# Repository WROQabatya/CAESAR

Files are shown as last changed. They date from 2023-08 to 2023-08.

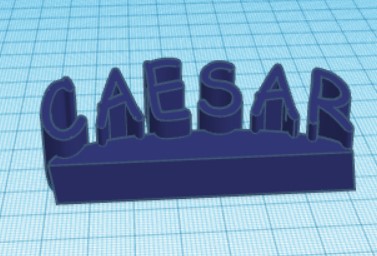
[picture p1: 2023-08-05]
3dDesignes/image/RoboName.jpg

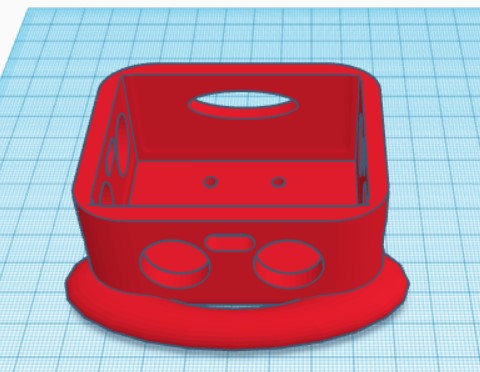
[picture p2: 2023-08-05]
3dDesignes/image/dSensorMount.jpg

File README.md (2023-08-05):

Title: Microcontroller-Based Vehicle Control System: A C++ and Ultrasonic Sensor Approach

Introduction:
Our vehicle, named CAESAR , is an innovative microcontroller-based system that utilizes Arduino as the central controller. The Arduino microcontroller is programmed using C++ language to control various components, including motors, steering wheels, and sensors like Ultrasonic sensors. We have opted not to incorporate a Raspberry Pi or gyro sensor in our project.

C++ Code Structure:
The C++ code is thoughtfully organized into sections, each dedicated to specific functionalities.

Servo Motor and Ultrasonic Sensor Control:
We employ libraries to control the servo motor movement and interface with Ultrasonic sensors. These sensors play a crucial role in detecting obstacles and determining the vehicle's movement directions.

Global Variables:
Descriptive global variables, such as "normalSpeed" and "turnSpeed," are defined to manage the vehicle's speed and turning behavior, respectively.

Ultrasonic Sensor Functions:
Key functions, including "turnLeft()" and "turnRight()", leverage readings from Ultrasonic sensors to determine the appropriate direction for the vehicle. The Ultrasonic sensor values guide counter-clockwise and clockwise turns. Additionally, functions like "getDistance()", "getForward()", "getBack()", "getRight()", and "getLeft()" are implemented to read data from individual Ultrasonic sensors.

Setup and Main Logic:
The "setup()" function handles necessary configurations for the system, while the main logic is implemented inside the "loop()" function. The loop function continuously executes, enabling the vehicle to react to real-time changes detected by the Ultrasonic sensors.

No Gyro Sensor Integration:
In contrast to some designs, we have opted not to use a gyro sensor in our project. Instead, we focus solely on utilizing Ultrasonic sensors for obstacle detection and navigation.

Conclusion:
Our microcontroller-based vehicle control system showcases the capabilities of Arduino and C++ programming in managing various vehicle components. With Ultrasonic sensors serving as the primary input, our CAESAR vehicle demonstrates reliable obstacle avoidance and navigation capabilities.

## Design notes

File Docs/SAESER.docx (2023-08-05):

Stages of making a SAESER

ENG.AHMAD

HISHAM

MAJD

KANAAN

Introduction

WRO Future Engineers -Selft Driving car

selft driving car

When we talk about competitions that are concerned with the field of robotics, we must talk about The World Robot Olympiad (WRO) , which was launched for the youth category. China, Japan and Singapore, and these four countries are the founding countries of this Olympiad (now known as the WRO Advisory Board).

Problems

Our Competition:

We are competing in this competition in the Future Engineers category It revolves around designing a self-driving robot that can overcome the obstacles and problems it encounters in the least possible time, based on artificial intelligence and machine learning.

Contest idea:

The environment of this competition consists of a circuit surrounded by an external wall, inside which there is an internal wall. As for the competition, it consists of one stage in which the robot runs at a rate of 3 laps that it must complete in 3 minutes as a maximum.

STAGE

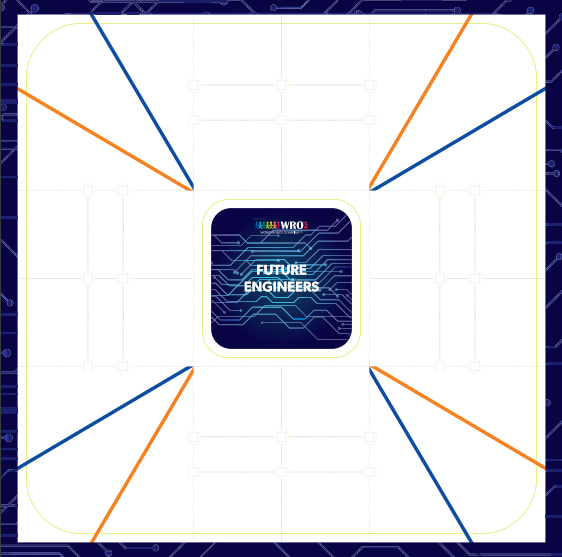
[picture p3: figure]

Hypotheses

During our work and the manufacture of the robot, we encountered many problems, and it is normal for such matters to happen in this field. They must be resolved with patience, effort, research, and the use of time to find an accurate solution.

Hypotheses and questions:

How to identify the appropriate electronics and employ them properly?

How can machine learning be employed in the work of a robot?

How can you complete the race and avoid mistakes?

How can a software algorithm be found to make the performance professional?

How to find solutions to all possible possibilities?

Methodology

The design phase of the robot was divided into 2 parts

namely:

. Hardware 1

. Software2

First, the electronics were selected according to the "WRO" competition.

Secondly, we start creating 3D designs to be placed on most electronic pieces to install or otherwise.

Thirdly, we start installing the 3D designs of electronics on the robot and conducting a preliminary test for it.

Finally, we start writing the software code and employing these electronics in it.

The Electronics:

Use Electronics:

• Arduino Mega 2560

• L298N Motor Driver

• Ultrasonic Distance sensor x(4)

• DC gear motor 12v 60 RPM

• s3003 servo motor

• Power Supply

• Wires

• Wheels

Arduino Mega 2560:

• Microcontroller: ATmega2560.

• INPUT VOLTAGE (LIMIT): 6-20V

• Flash Memory: 256 KB of which 8 KB used by bootloader.

• Analog In Pin: 16.

• Digital I/O Pins: 54 (of which 15 provide PWM output).

• Weight: 37g.

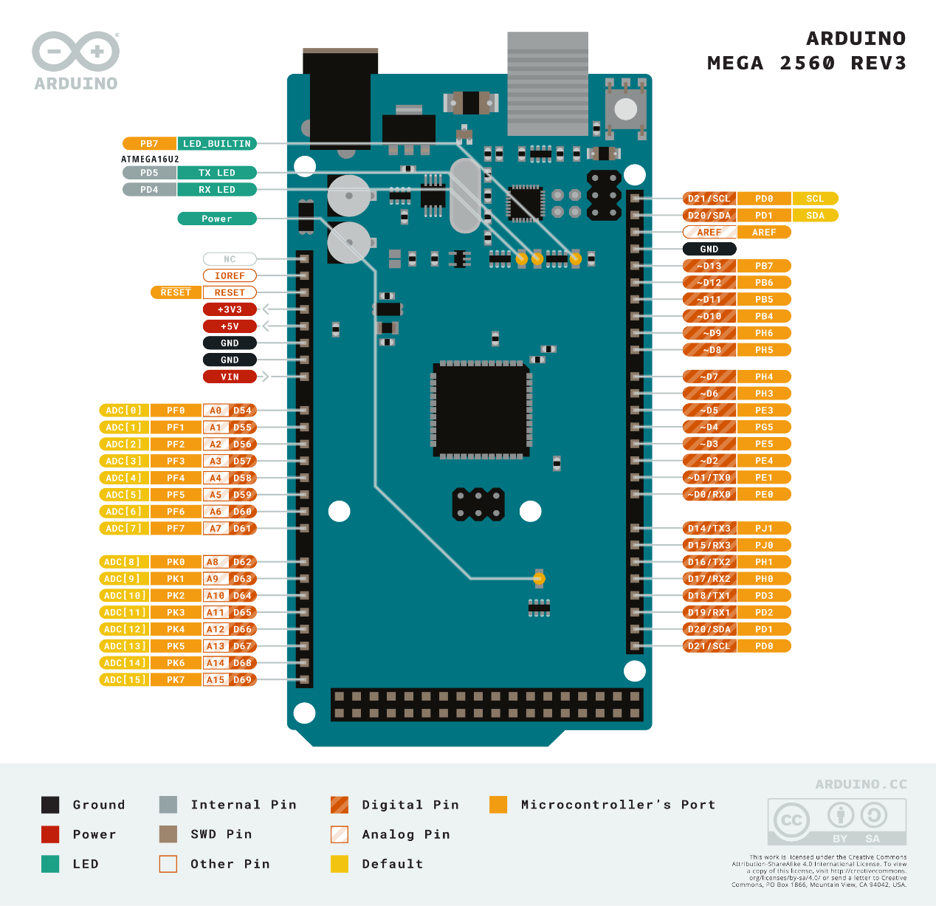
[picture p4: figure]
صورة تحتوي على نص, لقطة شاشة, برمجيات, دائرة كهربائية تم إنشاء الوصف تلقائياً

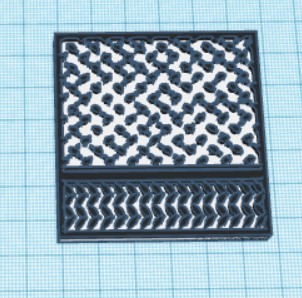
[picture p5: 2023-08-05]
3dDesignes/image/kofeia.jpg

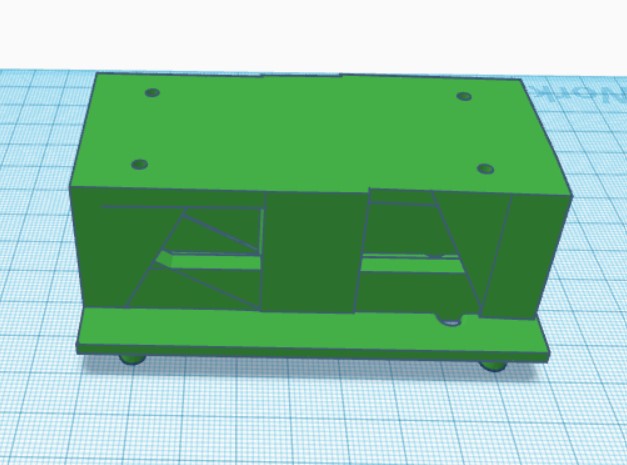
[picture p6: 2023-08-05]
3dDesignes/image/ArduinoHolder.jpg

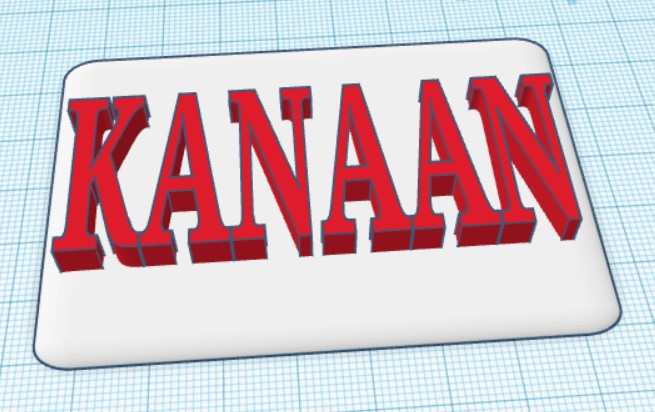
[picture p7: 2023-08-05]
3dDesignes/image/TeemName.jpg

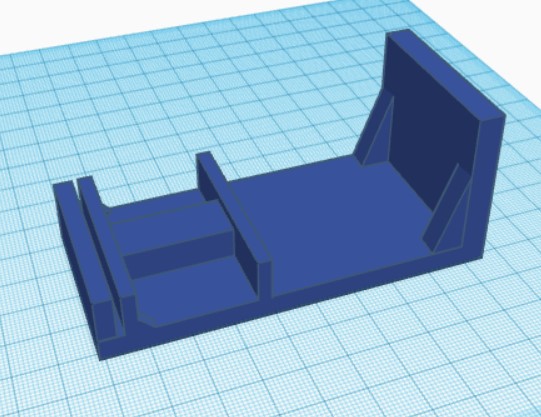
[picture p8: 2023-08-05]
3dDesignes/image/AudioStand.jpg

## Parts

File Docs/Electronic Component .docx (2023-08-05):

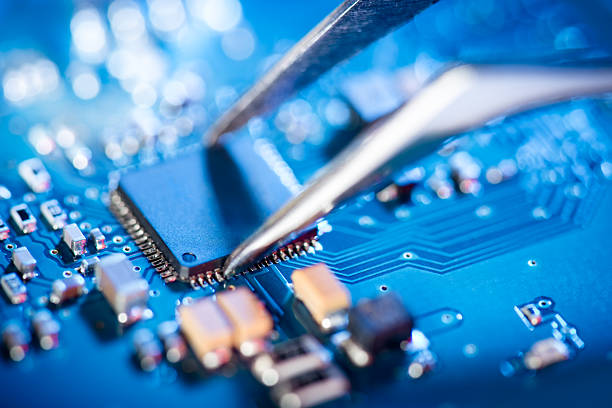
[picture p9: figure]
صورة تحتوي على دائرة كهربائية, الهندسة الإلكترونية, مكون إلكتروني, مكونات الدائرة الكهربائية تم إنشاء الوصف تلقائياً

Electronic Parts

KANAAN TEAM

Content

- Main Diagram
- Arduino Mega 2560
- L298N Motor Driver
- DC voltage Buck
- DC Encoder Motor
- Servo Motor
- Battery

Main Diagram

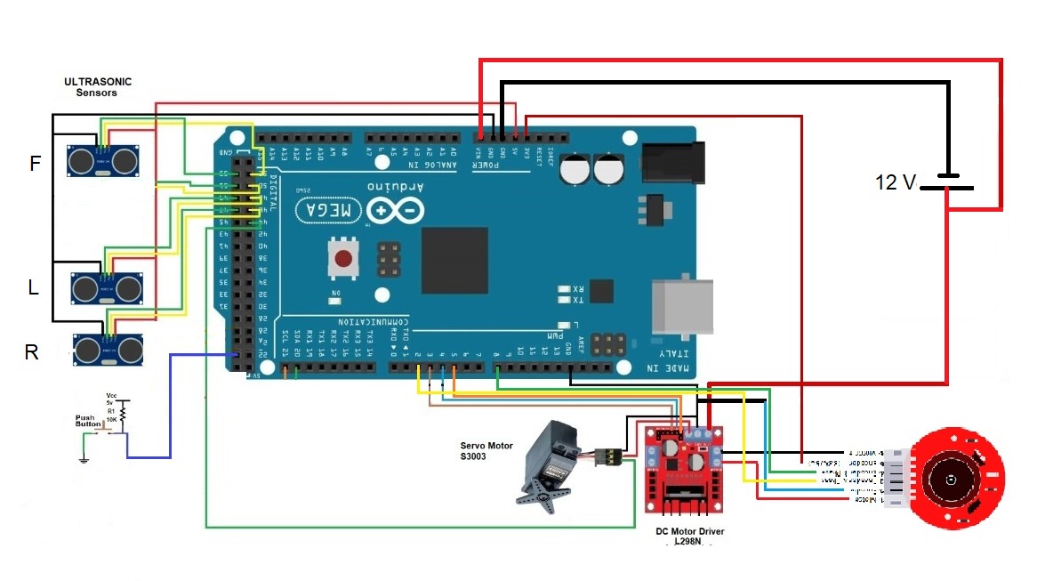
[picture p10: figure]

The electronic diagram illustrates the interconnection mechanism between the controllers and how the Arduino controller is linked to the Ultrasonic sensors and motor driver. The motor driver is responsible for governing both the DC motor and the servo.

Arduino Mega 2560

The Arduino microcontroller plays a pivotal role in controlling diverse electronic components through the following processes:

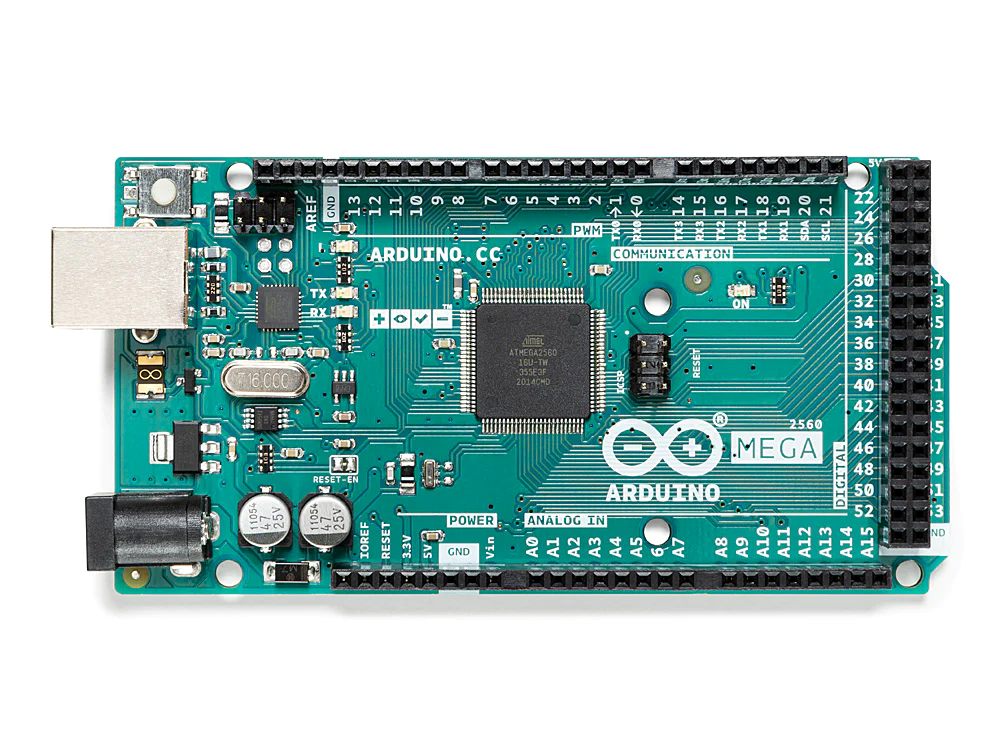
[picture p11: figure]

Initially, it supervises the servo motor and DC motor by sending commands to the motor driver.

Subsequently, it measures the distances recorded by the front, back, and side ultrasonic sensors.

Furthermore, it regulates the RGB LEDs, granting the ability to manipulate their colors.

Lastly, it detects the push button to activate the vehicle's functions. It is noteworthy that the Arduino Nano has been replaced by the Arduino Mega. This change was made due to the benefits of using the Arduino Mega, which offers individual ports for each function without requiring multiplexing. This configuration allows for more efficient use of PWM (Pulse Width Modulation) capabilities. Additionally, the system reads the switch to facilitate code changes.

L298N Motor Driver

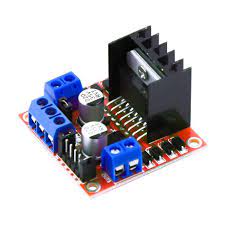
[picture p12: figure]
صورة تحتوي على مكونات الدائرة الكهربائية, مكون إلكتروني, دائرة كهربائية, مكون الدائرة السلبية تم إنشاء الوصف تلقائياً

The motor driver serves a dual purpose, enabling both speed control for the DC motor and facilitating forward and backward motion, while also governing the movement of the servo motor.

Ultrasonic Sensors

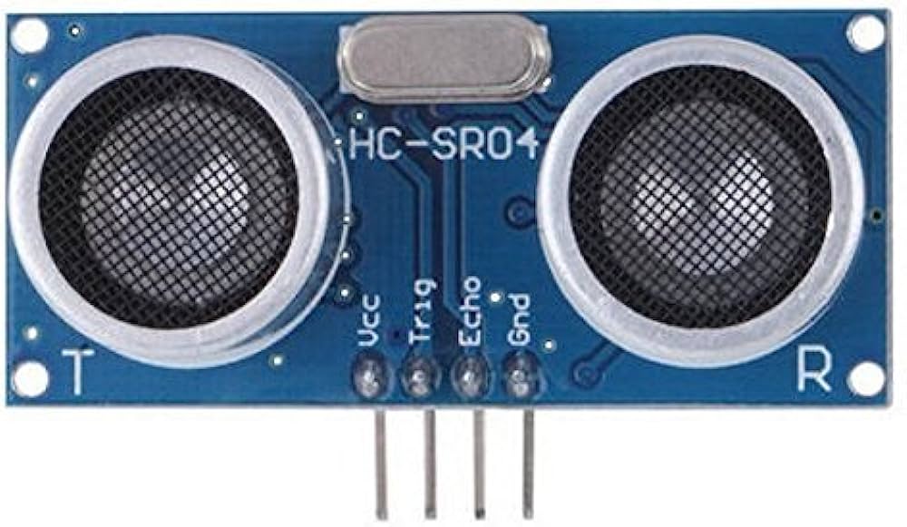
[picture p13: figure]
صورة تحتوي على الإلكترونيات, مكبر الصوت, معدات الصوت, صندوق الصوت تم إنشاء الوصف تلقائياً

A trio of sensors is employed, with one positioned at the front and two on the sides. These ultrasonic sensors play a crucial role in determining distances and the direction of the vehicle's movement, along with providing valuable insights into other pertinent aspects.

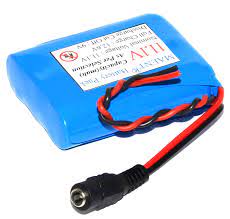
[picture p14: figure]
صورة تحتوي على نص, كابل, البطارية تم إنشاء الوصف تلقائياً

Battery

The vehicle relies on a battery to supply essential power. This battery configuration comprises three lithium batteries interconnected in series.

DC voltage Buck

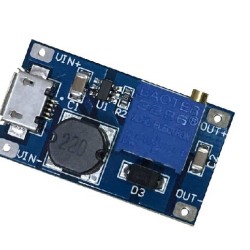
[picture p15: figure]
صورة تحتوي على مكون إلكتروني, الهندسة الإلكترونية, الإلكترونيات, مكونات الدائرة الكهربائية تم إنشاء الوصف تلقائياً

This circuit is designed to reduce voltage, as it was used to supply power to the Servo Motor.

DC Encoder Motor

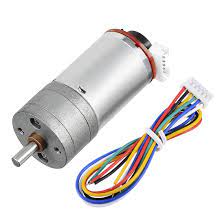
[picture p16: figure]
صورة تحتوي على كابل, أسطوانة, الأسلاك الكهربائية, فضة/ لون فضي تم إنشاء الوصف تلقائياً

The DC motor is physically linked to the rear wheels, enabling the vehicle's motion.

The reason for using an Encoder is to monitor the motor's direction and movement, which proves instrumental in controlling the overall movement of the vehicle.

صورة تحتوي على نص, أداة, كابل, البطارية تم إنشاء الوصف تلقائياً

Servo Motor

The servo motor assumes the responsibility of directing the vehicle by manipulating the steering wheel.

THANK YOU

KANAAN TEAM

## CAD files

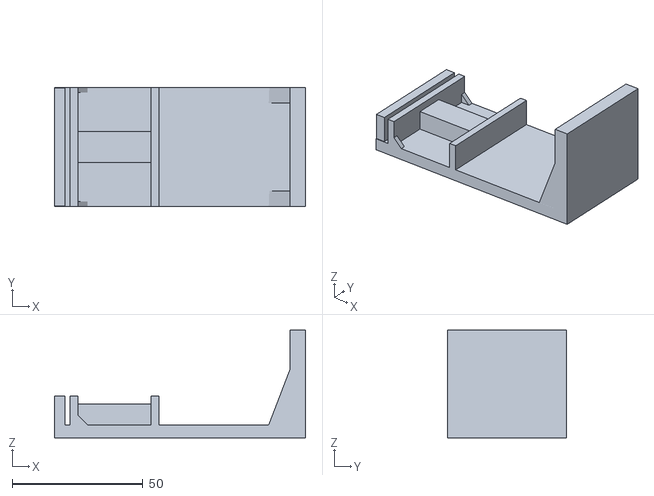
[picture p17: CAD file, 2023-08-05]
3dDesignes/STL/AudioStand (1).stl
96.0 x 45.5 x 41.3

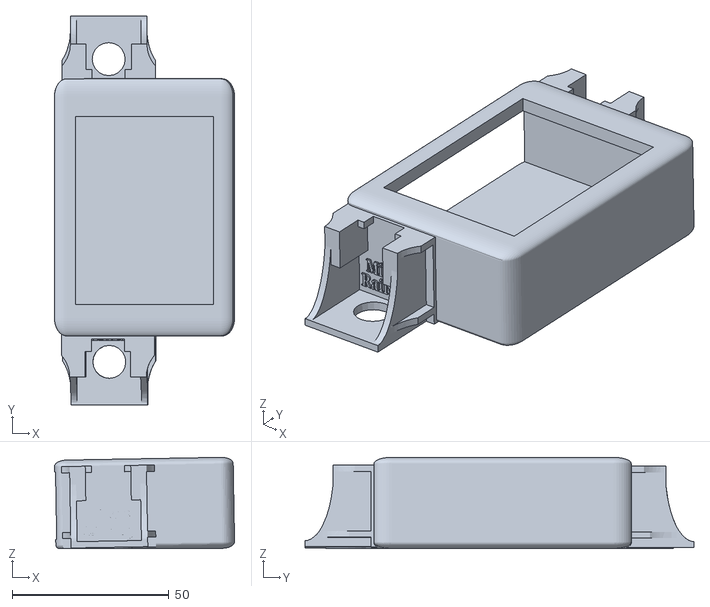
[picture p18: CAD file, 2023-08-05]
3dDesignes/STL/BattaryHolder (2).stl
57.4 x 124.0 x 29.1

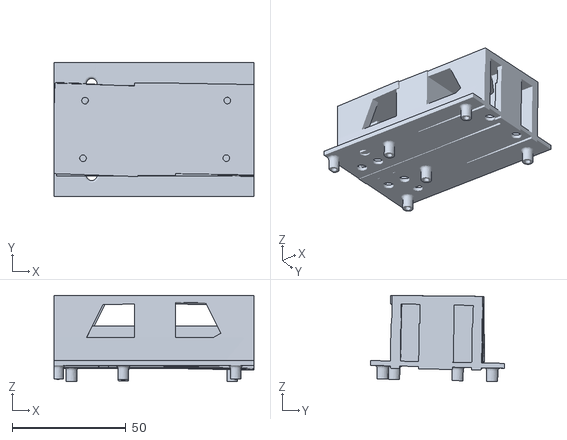
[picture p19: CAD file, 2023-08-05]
3dDesignes/STL/ArduinoHolder23 (1).stl
88.1 x 59.0 x 37.9

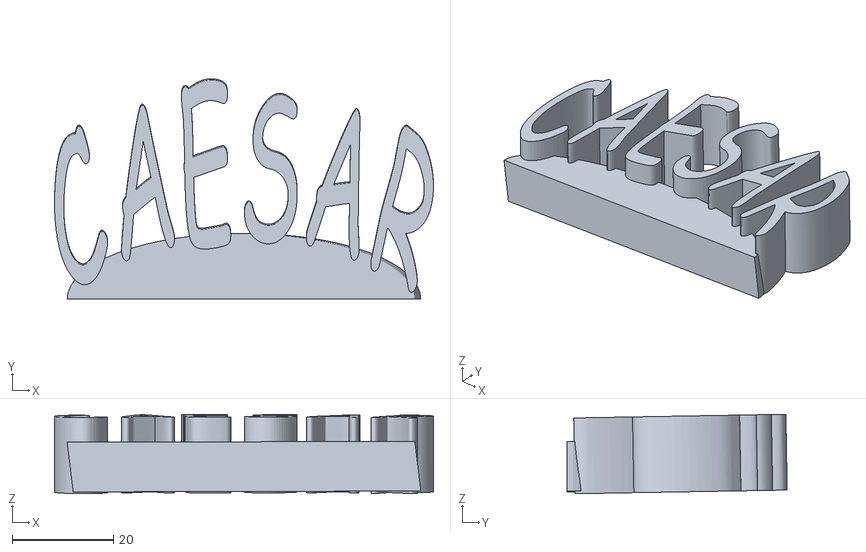
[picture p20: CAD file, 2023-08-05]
3dDesignes/STL/RoboName23 (2).stl
75.0 x 43.6 x 15.7

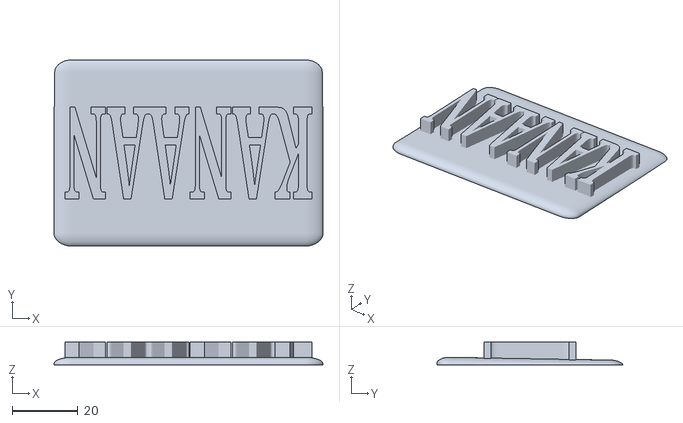
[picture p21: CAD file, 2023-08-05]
3dDesignes/STL/TeemName (1).stl
82.0 x 56.8 x 7.00

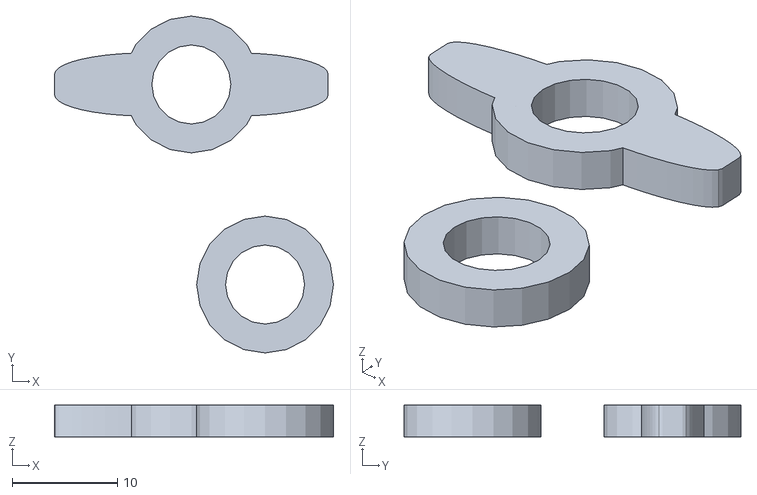
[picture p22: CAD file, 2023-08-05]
3dDesignes/STL/buttonAndLedMount.stl
26.5 x 32.0 x 3.00

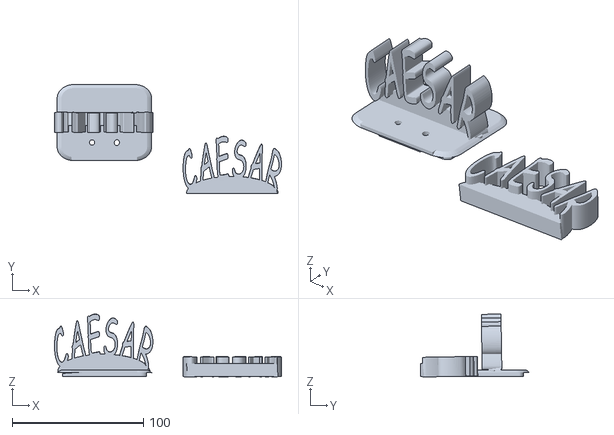
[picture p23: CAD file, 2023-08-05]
3dDesignes/STL/SensorsCover (1).stl
173.0 x 83.0 x 48.0

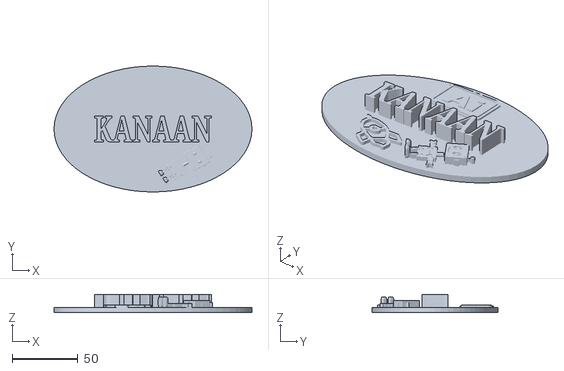
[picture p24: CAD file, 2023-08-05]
3dDesignes/STL/TeemLogo.stl
151.0 x 96.0 x 14.0

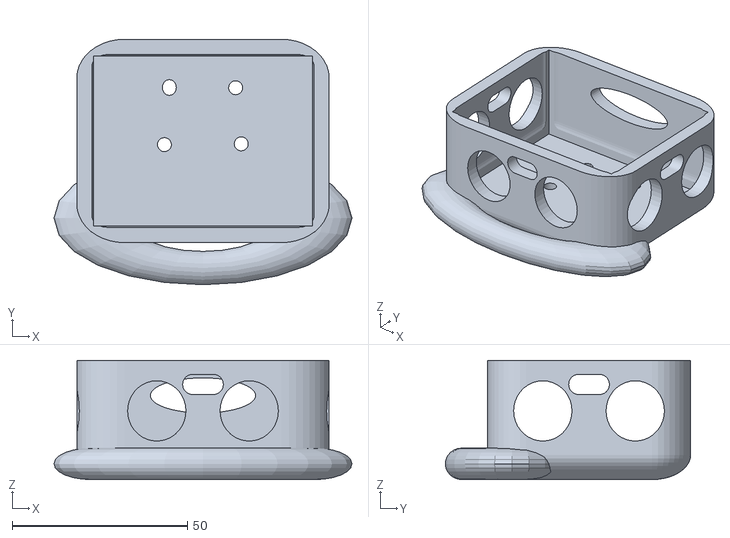
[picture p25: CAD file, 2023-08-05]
3dDesignes/STL/dSensorMount.stl
85.0 x 70.0 x 34.0

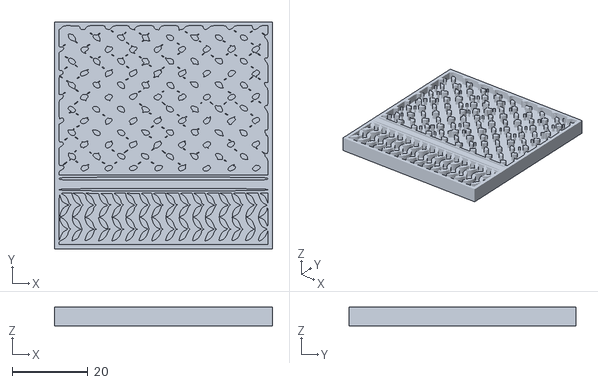
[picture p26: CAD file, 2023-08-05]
3dDesignes/STL/kofeia.stl
57.5 x 60.0 x 5.00

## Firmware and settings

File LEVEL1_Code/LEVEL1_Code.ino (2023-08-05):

#include <SoftwareSerial.h>
#include"DFRobotDFPlayerMini.h"

#include <Servo.h>
#include <math.h>
Servo Stearing ;

SoftwareSerial audioSerial(30, 31); // RX, TX
DFRobotDFPlayerMini myDFPlayer;

void speakInit(){
  audioSerial.begin(9600);
  if (!myDFPlayer.begin(audioSerial)) { Serial.println(F("DFPlayer Mini Error."));  }
  myDFPlayer.setTimeOut(500); //Set serial communictaion time out 500ms
  myDFPlayer.volume(25);
  }


int normalSpeed = 250;
int turnSpeed = 225;
int currentSpeed = 100;
int reverseSpeed = 50 ;
int isturn=0;
int canTurn=0;
int counterClockWise = 0;  // 0 init  1 clock  2 counterclockwise
int needTurn=0;
int LastState=0;
int CodeMOD=0;

volatile long encoderPos = 0;
String state ="9";
float distance;

// Motors 

#define encodPinA1      2                       // Quadrature encoder A pin
#define encodPinB1      8                       // Quadrature encoder B pin
#define PWM             5
#define M1              4                       // PWM outputs to L298N H-Bridge motor driver module
#define M2              3
#define Motor 44
#define BTN 13
#define MOD 14
#define LEDG 12
#define LEDB 11
#define LEDR 10

// distance 

#define TRIGGERF 52   //D6
#define ECHOF 53      //D7
#define TRIGGERL 48 //A0
#define ECHOL 49    //A1
#define TRIGGERR 50 //A2
#define ECHOR 51    //A3


unsigned long period;

// --- end distance

int x=0;
int counter = 0 ;


void setup() {
  // put your setup code here, to run once:

  pinMode(LEDR,OUTPUT);
  pinMode(LEDG,OUTPUT);
  pinMode(LEDB,OUTPUT);
  pinMode(MOD,INPUT);
  pinMode(BTN,INPUT);



  Stearing.attach(Motor);

  pinMode(M1,OUTPUT);
  pinMode(M2,OUTPUT);
  pinMode(encodPinA1, INPUT_PULLUP);                  // quadrature encoder input A
  pinMode(encodPinB1, INPUT_PULLUP);                  // quadrature encoder input B
  attachInterrupt(0, encoder, FALLING);               // update encoder position
  TCCR1B = TCCR1B & 0b11111000 | 1; 
 // set 31KHz PWM to prevent motor noise
  pinMode(BTN,INPUT);

  // distance 

  pinMode(ECHOL,INPUT);
  pinMode(TRIGGERL,OUTPUT);

 
  
  pinMode(ECHOF,INPUT);
  pinMode(TRIGGERF,OUTPUT);
  
  pinMode(ECHOR,INPUT);
  pinMode(TRIGGERR,OUTPUT);
  
  // -end distance

  Serial.begin (115200);  
  pinMode(Motor,OUTPUT);

 

  resetStearings(); 
 
if (!digitalRead(MOD)){digitalWrite(LEDB,HIGH);CodeMOD=0;}
else{digitalWrite(LEDG,HIGH);CodeMOD=1;}

   speakInit();
   myDFPlayer.play(3);

}
//   Distance Fun


void encoder()  {                                     // pulse and direction, direct port reading to save cycles
  if (PINB & 0b00000001)    encoderPos--;             // if(digitalRead(encodPinB1)==HIGH)   count ++;
  else                      encoderPos++;             // if(digitalRead(encodPinB1)==LOW)   count --;
}

float obstacleDist(int trig,int echo){
 digitalWrite(trig,LOW);
 delayMicroseconds(3);
 digitalWrite(trig,HIGH);
 delayMicroseconds(10);
 digitalWrite(trig,LOW);
 period=pulseIn(echo,HIGH);
 distance=float(period)/58.8;
  return distance;
  
  }


// End Distance Fun


// functions for dc motor

void Run(int out) {                                // to H-Bridge board
  if (out > 0) {
    analogWrite(PWM,out);
    digitalWrite(M1, HIGH);                             // drive motor CW
    digitalWrite(M2, LOW);
  }
  else {
     analogWrite(PWM,out);
     digitalWrite(M1, LOW);                             // drive motor CW
     digitalWrite(M2, HIGH);                        // drive motor CCW
  }
  
}


// functions to read ultrasonic sensors 
int getForward ()
{


int i = 0; 
int f = 0;
int tmp = 0;
tmp = obstacleDist(TRIGGERF,ECHOF);
while (i < 2)
{
  i++;
tmp = (obstacleDist(TRIGGERF,ECHOF) + tmp)/2;
}
 if (tmp > 250 ) {
    tmp = 150 ;  
  }

return  tmp;
}

int getLeft ()
{

int i = 0; 
int L = 0 ;
int  tmp = obstacleDist(TRIGGERL,ECHOL);
while (i < 2)
{

  i++;
  L=obstacleDist(TRIGGERL,ECHOL);
  if (L>tmp) {tmp=L;}
  
 
}
 
return tmp;
}

int getRight ()
{

int i = 0; 
int tmp = 0;
int R=0;
tmp = obstacleDist(TRIGGERR,ECHOR);
while (i < 2)
{
  i++;
  R=obstacleDist(TRIGGERR,ECHOR);
  if (R>tmp) {tmp=R;}

}
 

return tmp;
}




// end ultrasonic functions






void resetStearingi(){
  Stearing.write(120);
  MyDelay(2);
  if (counterClockWise == 0 || counterClockWise == 1)
  {
  Stearing.write(85);
  }
  else if (counterClockWise ==2)
  {
  Stearing.write(90);
  }
}

void resetStearings(){
  Stearing.write(120);
  MyDelay(2);
   
  Stearing.write(90);
  
}





void straightBack (int delta) 
{

 
  if (LastState == 0 || LastState == 1 ){

      encoderWalkStraight1(50,999);
      encoderPos = 0;
      Stearing.write(45);
      encoderWalkStraight1(53,999);
      encoderTurnBack(67 +delta);  
      resetStearingi();
      encoderWalkStraight1(10,999);
      Run(0);
      MyDelay(2);
      
      }
      else if (LastState == 5 )
      {
        
      encoderWalkStraight1(50,999);
      encoderPos = 0;
      Stearing.write(45);
      encoderWalkStraight1(53,999);      
      encoderTurnBack(10 +delta);   
      resetStearingi();
      encoderWalkStraight1(15,999);
      Run(0);
      MyDelay(2);
      
        }
counter++;
   
}


void straightBackRight (int delta) 
{
  int deltaStrightDifferenceVar = deltaStrightDifference(10);
  if (LastState == 5 || LastState == 0 ){
    
      encoderWalkStraight1(80,999);
      encoderPos = 0;
      Stearing.write(120);
      encoderWalkStraight1(27,999);      
      encoderTurnBackRight(47 +delta);  
      resetStearingi();
      MyDelay(2);
      revEncoderSpeed(25,reverseSpeed);
      }
      else if (LastState == 1 )
      {

      encoderWalkStraight1(50,999);
      encoderPos = 0;
      Stearing.write(120);
      encoderWalkStraight1(27,999);     
      encoderTurnBackRight(35 +delta);
      resetStearingi();
      MyDelay(2);
      revEncoderSpeed(15,reverseSpeed);      
        }
counter++;
}

void turnLeft1(int delta)
{
     // L = .785 * 50 = 39.25   "   "
encoderPos = 0;
    Stearing.write(45);
    drvEncoderSpeed(60,turnSpeed);
    Stearing.write(120);
    double revEncoderVar = 40 + delta  ;
    revEncoderSpeed(revEncoderVar,reverseSpeed);
    resetStearingi();
    MyDelay(2);
    drvEncoderSpeed(20,turnSpeed);
    Run(0);
    counter ++ ;
}

void turnRight1(int delta){
    encoderPos = 0;
    Stearing.write(120);
    drvEncoderSpeed(55,turnSpeed);
    Stearing.write(45);
    double revEncoderVar = 50+ 2*delta ;
    revEncoderSpeed(revEncoderVar,reverseSpeed);
    resetStearingi();
    MyDelay(2);
    drvEncoderSpeed(20,turnSpeed);
    Run(0);
    counter ++ ;
  }

void readState()
{

 if (Serial.available() > 0  ) {
      state = Serial.readStringUntil('\n');
      if(state =="1" || state =="5" ){cases(state);}
      state="9";
      Serial.end();
      Serial.begin(115200);
}
else{cases("1");}
}


void encoderTurnBack(int angle)
{
  int dis = angle * 0.76;
  Stearing.write(120);
  revEncoderSpeed(dis,reverseSpeed);
}

void encoderTurnBackRight(int angle)
{
  int dis = angle * 1.35;
  Stearing.write(45);
  revEncoderSpeed(dis,reverseSpeed);
}

void encoderWalkStraight1(int distance,int side){
   if (counterClockWise == 1 ) {
   int getRightVar =0; 

   drvEncoderSpeed(distance /4,normalSpeed);
   if (LastState == 1 )   // from red pillars
   {
       drvEncoderSpeed(distance /4,normalSpeed);
       getRightVar = getRight();
          
       if (side !=999 )
       {
        
          if (getRightVar<15){Stearing.write(45);MyDelay(3);Stearing.write(120);MyDelay(1);resetStearingi();}
          else if (getRightVar>25){Stearing.write(110);MyDelay(2);Stearing.write(60);MyDelay(1);resetStearingi();}
       }
       
       drvEncoderSpeed(distance /2,normalSpeed);

       }
      else if (LastState==5)
       {     

        int  getLeftVar = getLeft();
        drvEncoderSpeed(distance /4,normalSpeed);
        getLeftVar = getLeft();  
        if (side !=999  )
            {      
             if (getLeftVar<17 ){  Stearing.write(120);MyDelay(1);Stearing.write(60);MyDelay(1);resetStearingi();}
            }
        drvEncoderSpeed(distance /2,normalSpeed);
        
        }
        else
        {    
         drvEncoderSpeed(distance, normalSpeed);
        }
   }



   //********************************************


   
   else if (counterClockWise == 2 ) {

    int getLeftVar =0; 

   drvEncoderSpeed(distance /4,normalSpeed);
   if (LastState == 5 )   // from red pillars
   {
       drvEncoderSpeed(distance /4,normalSpeed);
       getLeftVar = getLeft();
       if (side !=999 )
       {
        
          if (getLeftVar<15){  Stearing.write(120);MyDelay(2);Stearing.write(60);MyDelay(2);resetStearingi();}
          else if (getLeftVar>20){  Stearing.write(60);MyDelay(3);Stearing.write(120);MyDelay(2);resetStearingi();}
       }


       drvEncoderSpeed(distance /2,normalSpeed);

       }
      else if (LastState==1)
       {    
 
        int  getRightVar = getRight();
        drvEncoderSpeed(distance /2,normalSpeed);
        getRightVar = getRight();
        if (side !=999  )
            {      
              if (getRightVar<17 ){Stearing.write(60);MyDelay(3);Stearing.write(120);MyDelay(2);resetStearingi();}
              if (getRightVar>22 ){Stearing.write(120);MyDelay(3);Stearing.write(60);MyDelay(2);resetStearingi();}
             }
        drvEncoderSpeed(distance /2,normalSpeed);

        }
        else
        {    
         drvEncoderSpeed(distance ,normalSpeed);
        }
   }
  }

void encoderWalkStraight(int distance,int side, int speed0){
   if (counterClockWise == 1 ) {
  
  int getLeftVar; 
  int  getRightVar;
  int getFrontVar;
   
  drvEncoderSpeed(distance /2,speed0);
       
   
       
       getLeftVar = getLeft(); 
          
       if ( getLeftVar <20 && side != 999)
       {
   
         Stearing.write(110);MyDelay(2);Stearing.write(60);MyDelay(1);resetStearingi();
        
          
         
       }
       else {getRightVar = getRight();
        
        if (getRightVar <17 && side != 999 ){   
          
          Stearing.write(45);MyDelay(3);Stearing.write(120);MyDelay(1);resetStearingi();}
       }


       drvEncoderSpeed(distance /2,speed0);
       getLeftVar = getLeft(); 
          
     
       

   }
   //********************************************


   
   else if (counterClockWise == 2 ) {

    int getLeftVar; 
    int  getRightVar;
    int getFrontVar;
   
       drvEncoderSpeed(distance /2,speed0);
       
       
       getRightVar = getRight();
       if (getRightVar <25 && side != 999)
       {
         Stearing.write(45);MyDelay(3);Stearing.write(100);MyDelay(1);resetStearingi();
        
          
         
       }
       else {getLeftVar = getLeft();
       
        
        if (getLeftVar <13 && side != 999){ 
          
         
        Stearing.write(105);MyDelay(2);Stearing.write(60);MyDelay(1);resetStearingi();
       }
      
       }
      


       drvEncoderSpeed(distance /2,speed0);
     
       
       
   }
  }
int deltaStrightDifference(int edgeThreshold)    // to calculate distance between vehicle and outer edge
{

  int delta = getForward()-edgeThreshold ; 
  
    if (delta > 0)
    {

      return delta ; 
    }
    else 
    {
      return 0 ;
    }
}



int CalculateWalkDifferenceDegree ( double disSide1,double disSide2,double encoderDis)
{
  int result  = asin((disSide1 - disSide2)/encoderDis)*(180/3.14);
  

  return (result);
}

void turnLeft(int delta)
{
     
  
    double revEncoderVar = 84+ delta ;
    Stearing.write(30);
    drvEncoderSpeed(revEncoderVar,turnSpeed);
    resetStearingi();
    MyDelay(2);
    counter ++ ;
    encoderWalkStraight(50,999,normalSpeed);
  
}

void turnRight(int delta)


{
    double revEncoderVar = 76+ delta ;
    Stearing.write(120);
    drvEncoderSpeed(revEncoderVar,turnSpeed);
    resetStearingi();
    MyDelay(2);
    counter ++ ;
    encoderWalkStraight(50,999,normalSpeed);
  
  
  
  
  }

void MyDelay(int cct)
{
  for (int i=0;i<cct;i++)
  {
    delay(50);
    }
  }


void drvEncoderSpeed(int cm,int speed0)
{
  encoderPos=0;
if (cm>25){
float enc = (cm-20)/0.077;
 
while (encoderPos < int(enc))
{
  Run(speed0);
  }

}
else 
{
float enc = (cm)/0.23;
while (encoderPos < int(enc))
{
  Run(speed0);
  }
  
  
}
}

void revEncoderSpeed(int cm,int speed0)
{
 encoderPos=0;
if (cm>25){
float enc = (cm-20)/0.077;
 
while (encoderPos < int(enc))
{
  Run(-speed0);
  }

}
else 
{
float enc = (cm)/0.23;
while (encoderPos < int(enc))
{
  Run(-speed0);
  }
  
  
}
}



void drvEncoderSpeed1(int cm,int speed0)
{
  encoderPos=0;
if (cm>25){
float enc = 2.3*((cm-20)/0.077);
 
while (encoderPos < int(enc))
{
  Run(speed0);
  }

}
else 
{
float enc = 2.3*((cm)/0.23);
while (encoderPos < int(enc))
{
  Run(speed0);
  }
  
  
}
}

void revEncoderSpeed1(int cm,int speed0)
{
 encoderPos=0;
if (cm>25){
float enc = 2*((cm-20)/0.077);
 
while (encoderPos < int(enc))
{
  Run(-speed0);
  }

}
else 
{
float enc = 2*((cm)/0.23);
while (encoderPos < int(enc))
{
  Run(-speed0);
  }
  
  
}
}

double tempEdgeDistance0 = 0;
double tempEdgeDistance1 = 0;



void loop() {




  
  while(x==6){
    int getRightVar = getRight() ;
    Serial.println(getRightVar);
   // MyDelay(4);
    double d= 1.414 * getRightVar ;
    Stearing.write(120);
    drvEncoderSpeed1((d/4),turnSpeed);
    drvEncoderSpeed1((d/5),turnSpeed);
    resetStearingi();
    drvEncoderSpeed1((d/3),turnSpeed);
    drvEncoderSpeed1((d/10),turnSpeed);  
    Stearing.write(45);
    drvEncoderSpeed1((d/3),turnSpeed);
     drvEncoderSpeed1((d/4),turnSpeed);
    resetStearingi();
    drvEncoderSpeed1(10,turnSpeed);
    LastState = 1;
    x=17;
    
  }
  
  // put your main code here, to run repeatedly:

        int z=0;int rpt = 0;int g =0;

        while (x==10){
      //  drvEncoder (40);
        turnLeft(0)
        ;x=2;}

        
if (!digitalRead(BTN) && CodeMOD ==0){digitalWrite(LEDG,HIGH);
   MyDelay(20);
    normalSpeed = 250;
    turnSpeed = 230;
      
      while (x==0){


 

        
              while (counterClockWise == 0) {
              if (getLeft()>80.0) {turnLeft(10);counterClockWise = 1; tempEdgeDistance0 = getRight();tempEdgeDistance1 = getRight(); drvEncoderSpeed(5,turnSpeed); }
              else if (getRight()>80.0 ){turnRight(10);counterClockWise = 2;tempEdgeDistance0 = getLeft();tempEdgeDistance1 = getLeft();drvEncoderSpeed(5,turnSpeed);  }
              else if (getForward()<40){Run(0);encoderWalkStraight(2,999,turnSpeed);encoderPos = 0;}
              else {Run(turnSpeed);encoderPos = 0; }
              continue;
              }
        

            

                   
            if ((counterClockWise == 1))
                  {
                    
               if (g< 100){g= getLeft();}


               if (g>77.0)
                    {  g=0;
                     tempEdgeDistance1 = getRight();      
                     int t = CalculateWalkDifferenceDegree(tempEdgeDistance0,tempEdgeDistance1,100); 


                     turnLeft(t+8);
                     tempEdgeDistance0 = getRight();
 
                      }
                 else
                {
                  int getForwardVar =getForward();
                  if (getForwardVar<70){ encoderWalkStraight(4,999,turnSpeed);g= getLeft();MyDelay(1);}
                  else{  encoderWalkStraight(4,9999,normalSpeed); tempEdgeDistance1 = getRight(); }
                  
                  
                  
                  
                }
                if (counter > 11 ) 
                         {
                            int stopDistance = deltaStrightDifference(100);
                            drvEncoderSpeed((stopDistance/2)-5,normalSpeed);
                            x=1;
                            break;
                          }
                 }
                 
                 //endleft




                 
                 //**********************
                 
            else if (counterClockWise == 2 )
            {
              
               if (g< 100){g= getRight();}


               if (g>80.0)
                    {  g=0;
                     tempEdgeDistance1 = getLeft();      
                     int t = CalculateWalkDifferenceDegree(tempEdgeDistance0,tempEdgeDistance1,100); 
if (t>8) {t=0;}
if (t<8) {t=0;}
                     
                     turnRight(t+4);
                     tempEdgeDistance0 = getLeft();
 
                      }
                 else
                {
                  int getForwardVar =getForward();
                  if (getForwardVar<70){ encoderWalkStraight(4,999,turnSpeed);g= getRight();MyDelay(1);}
                  else{  encoderWalkStraight(4,9999,normalSpeed);}
                  
                  
                  
                  
                }
                if (counter > 11 ) 
                         {
                            int stopDistance = deltaStrightDifference(100);
                            drvEncoderSpeed(10,normalSpeed);
                            x=1;
                            break;
                          }
                 
                  
                  
  
              
            }
         





            
         
           

           
          }
          

}

//****************************** Stage 2 **************************************************/////////



if (!digitalRead(BTN) && CodeMOD == 1)
{
 normalSpeed = 230;
 turnSpeed = 190;
 reverseSpeed = 170;
 
 
 
 
 
 
 
 
 
 
 
 
 
 
 
 
 
 
 
 
 
 
 
 
 
 
 
 
 
 
 
 
 
 
 
 
 
 
 
 
 
 
 
 
 
 
 
 
 
 
 
 
 
 
 
 
 
 
 
 
 
 
 
 
 
 
 
 
 
 
 
 
 
 
 
 
 
 
 
 
 
 
 
 
 
 
 
 
 
 
 
 
 
 
 
 
 
 
 
 
 
 
 
 
 
 
 
 
 
 
 
 
 
 
 
 
 
 
 
 
 
 
 
 
 
 
 
 
 
 
 
 
 
 
 
 
 
 int g =0;
    MyDelay(20);
    resetStearingi();
       digitalWrite(LEDG,HIGH);
       while (x==0){
              while (counterClockWise == 0) {
              if (getLeft()>80.0) {turnLeft1(0);MyDelay(20);counterClockWise = 1; readState();tempEdgeDistance0 = getRight();tempEdgeDistance1 = getRight(); drvEncoderSpeed(5,turnSpeed); }
              else if (getRight()>80.0 ){turnRight(10);counterClockWise = 2;tempEdgeDistance0 = getLeft();tempEdgeDistance1 = getLeft();drvEncoderSpeed(5,turnSpeed);  }
              else if (getForward()<40){Run(0);encoderWalkStraight(2,999,turnSpeed);encoderPos = 0;}
              else {Run(turnSpeed);encoderPos = 0; }
              continue;
              }
        

            

                   
            if ((counterClockWise == 1))
                  {
                    
               if (g< 100){g= getLeft();}


               if (g>120.0)
                    {  g=0;
                     tempEdgeDistance1 = getRight();      
                     int t = CalculateWalkDifferenceDegree(tempEdgeDistance0,tempEdgeDistance1,100); 


                     
                      if (tempEdgeDistance1<40  &&  (LastState == 1 || LastState == 0) )
                      {
                       
                   //   drvEncoderSpeed(30,turnSpeed);
                      turnLeft1(0); 
                      }
                      else 
                      {
                        
                       straightBack(0);
                      }
                     tempEdgeDistance0 = getRight();
                     MyDelay(20);
                   //   cases("5");
                      readState();
 
                      }
                 else
                {
                  int getForwardVar =getForward();
                  if (getForwardVar<100){ Run(0); MyDelay(1);encoderWalkStraight1(2,999);g= getLeft();MyDelay(1);Serial.println("dd");}
                  else{  encoderWalkStraight1(4,9999); tempEdgeDistance1 = getRight(); }
                  
                  
                  
                  
                }
                if (counter > 11 ) 
                         {
                            int stopDistance = deltaStrightDifference(100);
                            drvEncoderSpeed((stopDistance/2),normalSpeed);
                            x=1;
                            break;
                          }
                 }
          
      }}


Run(0);
}
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
